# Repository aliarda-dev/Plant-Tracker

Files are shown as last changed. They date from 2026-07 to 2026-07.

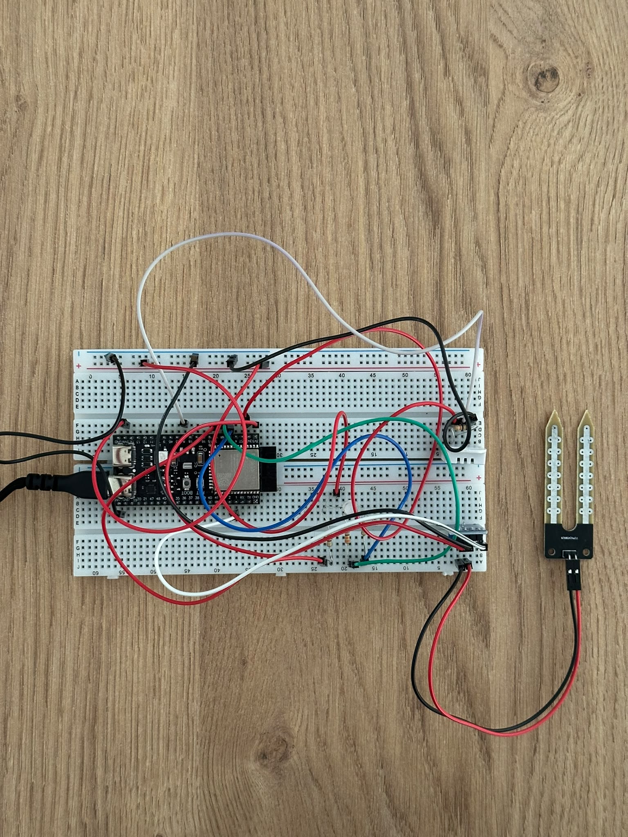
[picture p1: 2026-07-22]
Media/plant-tracker.jpeg

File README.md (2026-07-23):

***Plant Tracker***

DHT22 ve FC28 sensörlerini entegre çalıştırarak kodumda yazdığım koşullar sağlandığında telegram botuna mesaj yollayan bir IoT projesi. İlk IoT proje deneyimim oldu zorlandığım taraf ESP32'nin wifiye bağlaması oldu, buna gerçekten çok vakit ayırdım.

***Uğraştığım Hatalar***

* C make list mantığını biraz geç öğrendim bu yüzden compiler sürekli hata veriyordu
* Https sertifika hataları
* Main task overflow hatası, menucfonig defaultu 3584 bytedi ben bunu 8192 yaptim (https istekleri buna neden oldu)
* DHT22 Phase B hatası aldım. Çözümü delay kullanmak oldu wifi istekleri ile aynı anda kullanılınca sıkıntı çıkarabiliyor.
* RGB led 5V bağlı iken yanmıyordu. Sebebi ESP32'nin 5V çıkışının aktif olmamasıydı. Redditte dolaşmaktan projeden bıkmaya başlamıştım sonrasında kart üstündeki N-OUT köprüsünü öğrendim 5V güç çıkışı için bunun lehimlenmesi gerekiyormuş onu lehimledim.
* ve daha niceleri

***Donanım***

* ESP32S3
* DHT22 (Sıcaklık ve Nem sensörü)
* FC-28 (Toprak Nem Sensörü)
* Ortak Anot RGB Led
* 4x330R Direnç (Üç tanesi rgb led için geriye kalan bir tanesi de dht sensoru için)

***Nasıl Çalışır?***

* DHT22 sensöründen sıcaklık ve nem değerleri okunur ve gerekli variablelara aktarılır
* FC28 sensöründen nem değeri okunarak gerekli variablea aktarılır
* Wifi bağlantısı kurulur
* Belirlenen aralıkta telegram botuna bitkinin içinde bulunduğu odanın sıcaklık ve nem değerleri gönderilir
* Toprak nem değeri eşik değeri altına düşerse bota uyarı mesajı yollanır
* Sıcaklık ve nem değerleri belirlenen değerler dışına saparsa bota başka bir uyarı mesajı yollanır
* Zamanlama kontrolu olarak esp_timer_get_time() kullanılır

***Teknik Notlar***

* Wifi bağlantısı ve Telegram API kısmında AI'dan destek aldım. İlk IoT projem olduğu için ESP'nin ağ yapısını tek başıma kurmakta zorlandım. Kodu tamamladıktan sonra birkaç gün boyunca kullandığım her fonksiyonu ve event yapısını tek tek inceleyerek nasıl çalıştığını öğrenmeye çalıştım.

***Geliştirme Fikirleri***

* ESP32 hafızası üzerinde dosya açılarak hataların geldiği saatler data olarak tutulabilir.

🎥 Proje Demo

https://github.com/user-attachments/assets/45af9969-96e5-4f03-8e86-a813d68cf8f5

📷 Proje PCB Medyası

plant-tracker4

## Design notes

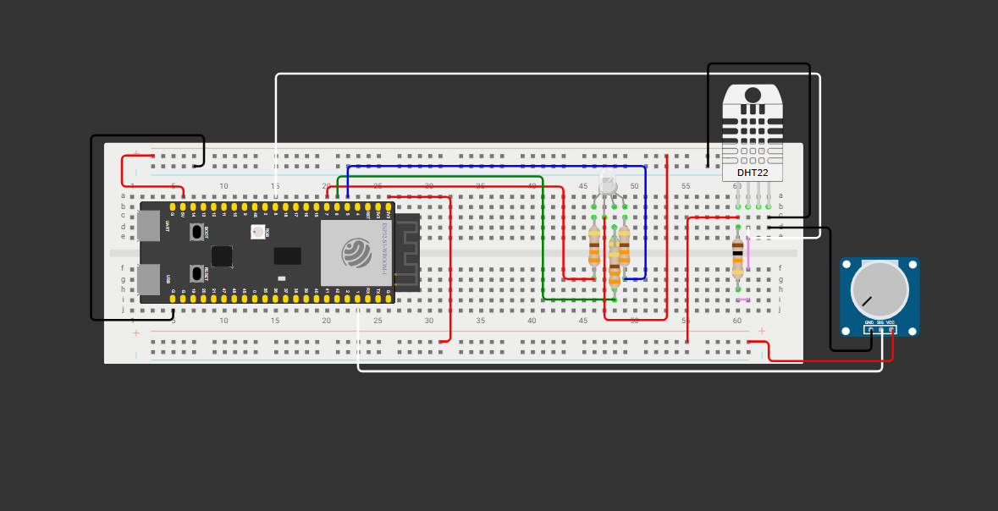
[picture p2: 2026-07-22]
Media/teoric-plant-tracker.png

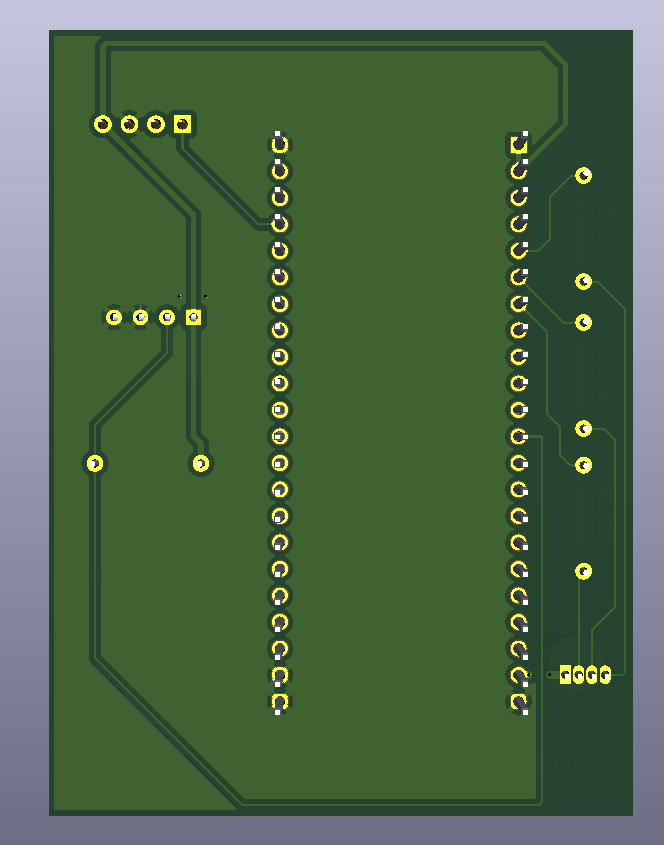
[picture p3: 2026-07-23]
PCB/PCB Media/plant-tracker2.png

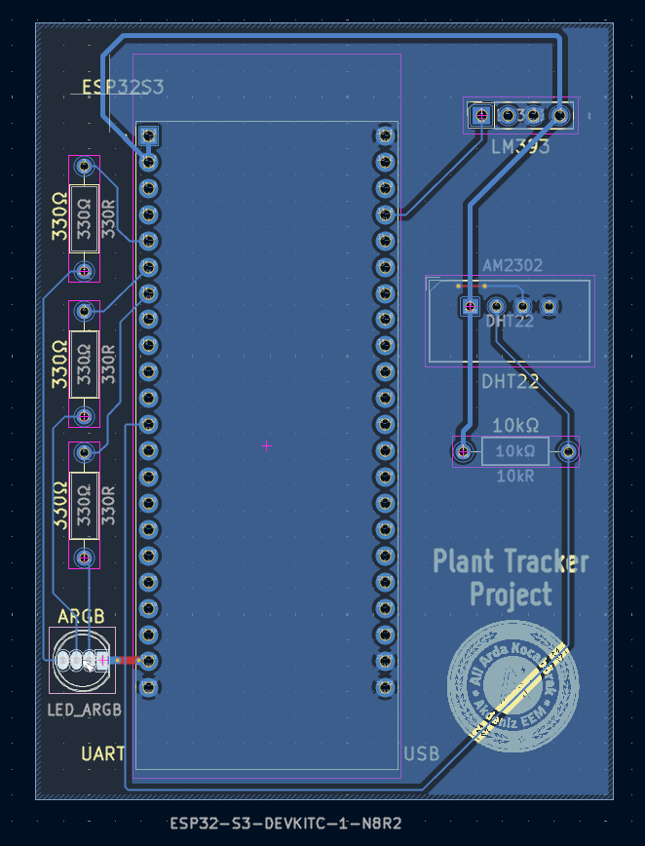
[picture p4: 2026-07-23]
PCB/PCB Media/plant-tracker3.png

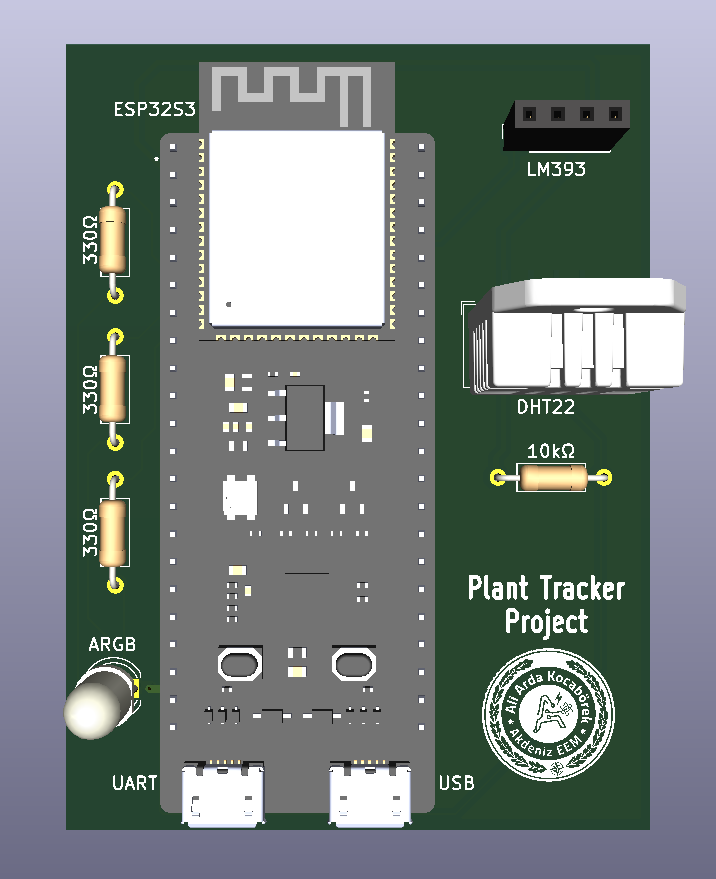
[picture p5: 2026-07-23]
PCB/PCB Media/plant-tracker1.png

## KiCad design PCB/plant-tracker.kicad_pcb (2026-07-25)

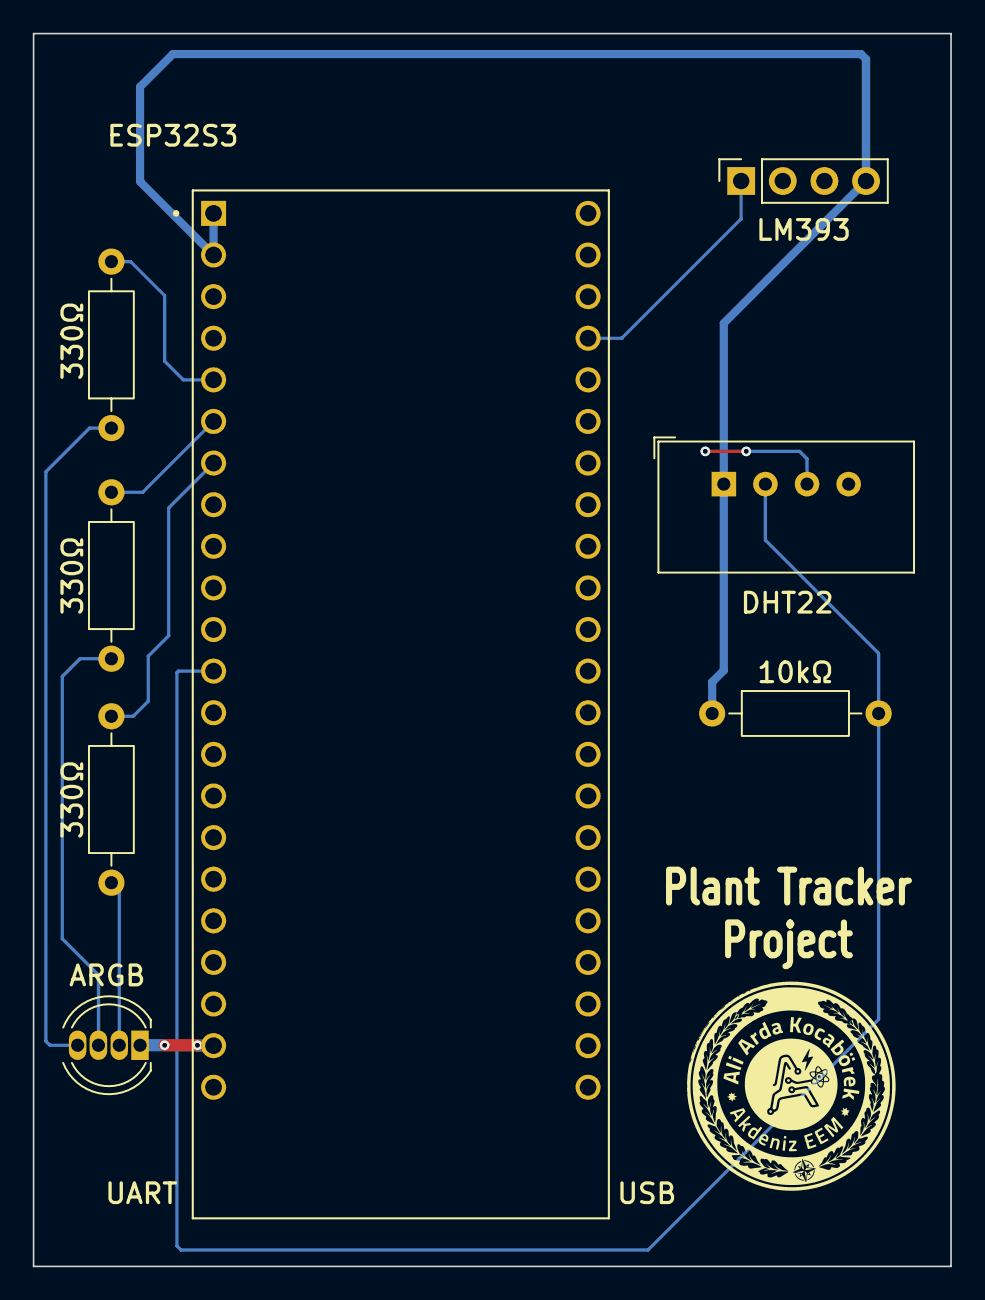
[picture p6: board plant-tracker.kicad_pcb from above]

Board: 2 copper layers, 56.0 x 75.2 mm, 8 parts (0 on the bottom side), 11 nets.

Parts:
10kΩ: 10kR; R_Axial_DIN0207_L6.3mm_D2.5mm_P10.16mm_Horizontal
330Ω, 330Ω#2, 330Ω#3: 330R; R_Axial_DIN0207_L6.3mm_D2.5mm_P10.16mm_Horizontal
ARGB: LED_ARGB; LED_D5.0mm-4_RGB
DHT22: AM2302; ASAIR_AM2302_P2.54mm_Vertical
ESP32S3: ESP32-S3-DEVKITC-1-N8R2; ESP32S3
LM393: PinSocket_1x04_P2.54mm_Vertical

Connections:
3.3V: 10kΩ.1, DHT22.1 (VDD), ESP32S3.J1_1 (3V3), ESP32S3.J1_2 (3V3), LM393.4 (VCC)
5V: ARGB.1 (A), ESP32S3.J1_21 (5V0)
G1: ESP32S3.J3_4 (GPIO1), LM393.1 (AO)
G5: 330Ω#2.2, ESP32S3.J1_5 (GPIO5)
G6: 330Ω#3.2, ESP32S3.J1_6 (GPIO6)
G7: 330Ω.2, ESP32S3.J1_7 (GPIO7)
G8: 10kΩ.2, DHT22.2 (SDA), ESP32S3.J1_12 (GPIO8)
GND: DHT22.3 (GND), DHT22.4 (GND), ESP32S3.J1_22 (GND), ESP32S3.J3_1 (GND), ESP32S3.J3_21 (GND), ESP32S3.J3_22 (GND), LM393.3 (GND)
unnamed: 330Ω#2.1, ARGB.4 (BK)
unnamed: 330Ω#3.1, ARGB.3 (GK)
unnamed: 330Ω.1, ARGB.2 (RK)

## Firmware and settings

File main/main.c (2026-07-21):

#include <stdio.h>
#include <string.h>
#include <stdbool.h>
#include "freertos/FreeRTOS.h"
#include "freertos/task.h"
#include "driver/gpio.h"
#include "dht.h"

#include "esp_wifi.h" //Wifi surucusu
#include "nvs_flash.h" //Wifi surucusunun bazi bilgileri burada tutulur
#include "esp_event.h" //Wifi baglantısı saglandı mi gibi kontrol eden fonksiyonlara sahip
#include "esp_log.h"
#include "esp_netif.h" //Wifinin TCP/IP katmani hazirlanmasi

#include "esp_http_client.h" //htpp istegi icin (telegram kullanicaz)
#include "esp_crt_bundle.h"

#include "esp_adc/adc_oneshot.h" //Toprak nem sensoru icin

#include "esp_timer.h"









#define WIFI_SSID "xxxx" //wifi adi
#define WIFI_PASS "xxxx" //wifi sifre 

#define BOT_TOKEN "xxx" //telegram bot token
#define CHAT_ID "xxx" //telegram bot chat id

#define MAVI_LED GPIO_NUM_5
#define YESIL_LED GPIO_NUM_6
#define KIRMIZI_LED GPIO_NUM_7

#define TOPRAK_PIN ADC_CHANNEL_0
adc_oneshot_unit_handle_t adc_handle;


#define DHT22_PIN GPIO_NUM_8

static const char *TAG = "WiFi"; //Loglarda gorunecek isim
static void wifi_event_handler( //Espnin olay kontrol dongusunu kontrol eden fonksiyon
        void *arg,
        esp_event_base_t event_base,
        int32_t event_id,
        void *event_data);
void wifi_init(void);        

bool DhtDegerler (float*,float*);

void telegram_message(const char *);

void toprakPin_init(void);
void toprakDeger(int*);



void app_main(void){

    gpio_set_direction(MAVI_LED,GPIO_MODE_OUTPUT);
    gpio_set_direction(YESIL_LED,GPIO_MODE_OUTPUT);
    gpio_set_direction(KIRMIZI_LED,GPIO_MODE_OUTPUT);



    wifi_init();
    toprakPin_init();

    vTaskDelay(pdMS_TO_TICKS(8000));


    float sicaklik=0;
    float nem=0;

    int toprakDegeri=0;
    int esikDegeri=4000;

    
    int64_t son_mesaj_zaman_sicaklik=0;
    int64_t son_mesaj_zaman_sulama=0;
    int64_t son_mesaj_zaman_havaKosul=0;

    const int64_t mesaj_aralik=10*60*1000000; //10 dakika esp timera baglı bu hesaplama

     gpio_set_level(MAVI_LED,1);
     gpio_set_level(YESIL_LED,1);
     gpio_set_level(KIRMIZI_LED,1);


            

    while(1){

        bool sensor_kontrol=DhtDegerler(&sicaklik,&nem);

        vTaskDelay(pdMS_TO_TICKS(5000)); 

         if(sensor_kontrol==false){
            printf("DHT okunamadi hata!!\n\n");
            continue;
        }

        int64_t simdi=esp_timer_get_time();

        if(gpio_get_level(KIRMIZI_LED)==0){
            gpio_set_level(KIRMIZI_LED,1);
        }

        if(simdi-son_mesaj_zaman_sicaklik>mesaj_aralik){ //istedigimiz aralikta odanin kosullarini telegrama gonderecegiz

            char mesaj[50];

            snprintf(mesaj,sizeof(mesaj),"Sicaklik %.2f'C | Nem %.2f/100",sicaklik,nem);

            telegram_message(mesaj);

            son_mesaj_zaman_sicaklik=simdi;
        }





        toprakDeger(&toprakDegeri);
        vTaskDelay(pdMS_TO_TICKS(1000));

        if(toprakDegeri<esikDegeri && simdi-son_mesaj_zaman_sulama>mesaj_aralik/2){ //5 dakika
            telegram_message("Bitkinizi acil sulayin!!!");
            gpio_set_level(YESIL_LED,0);
            vTaskDelay(pdMS_TO_TICKS(500));
            gpio_set_level(YESIL_LED,1);

            son_mesaj_zaman_sulama=simdi;
        }

        if((sicaklik>40 || nem>80 || nem<30) && simdi-son_mesaj_zaman_havaKosul>mesaj_aralik/2){ //5 dakika
            telegram_message("Bitkiniz icin gerekli hava kosullari saglanmiyor!");
            gpio_set_level(KIRMIZI_LED,0);
            son_mesaj_zaman_havaKosul=simdi;
        }


        vTaskDelay(pdMS_TO_TICKS(5000));


        
    }

    



}






bool DhtDegerler (float* sicaklik,float* nem){

    esp_err_t sonuc = dht_read_float_data(DHT_TYPE_AM2301,DHT22_PIN,nem,sicaklik);

    if(sonuc==ESP_OK){
        printf("Sicaklik: %.2f\n",*sicaklik);
        printf("Nem: %.2f",*nem);
        vTaskDelay(pdMS_TO_TICKS(3500));
        return true;
    }

    else{
        printf("DHT duzgun calismiyor!!\n");
        return false;
    }

    

}



static void wifi_event_handler( //Espnin olay kontrol dongusunu kontrol eden fonksiyon
        void *arg,
        esp_event_base_t event_base,
        int32_t event_id,
        void *event_data){

            if(event_base==WIFI_EVENT && event_id==WIFI_EVENT_STA_START){ //Wifi surucusu basladiysa

                ESP_LOGI(TAG,"Wi-fi Basladi!\n\n");

                esp_wifi_connect();

            } 

            else if(event_base==WIFI_EVENT && event_id==WIFI_EVENT_STA_DISCONNECTED){

                ESP_LOGI(TAG,"Baglanti Koptu Tekrar Deneniyor...\n\n");

                esp_wifi_connect();
            }

            else if(event_base==IP_EVENT && event_id==IP_EVENT_STA_GOT_IP){ //IP alındıgında

                ESP_LOGI(TAG,"Wi-fi baglandi ve ip alindi...\n\n");
            }

        }



void wifi_init(void){

        nvs_flash_init(); //Flash bellek hazirlanmasi

        esp_netif_init(); //TCP_IP katmanini baslatilmasi

        esp_event_loop_create_default(); //Event sisteminin olusturulmasi

        esp_netif_create_default_wifi_sta(); //Station arayuzunun olusmasi


        wifi_init_config_t cfg = WIFI_INIT_CONFIG_DEFAULT(); //Wifi driver ayarlari

        esp_wifi_init(&cfg); //Driveri baslatma


        esp_event_handler_instance_register(WIFI_EVENT,ESP_EVENT_ANY_ID,&wifi_event_handler,NULL,NULL); //Wifi Event Dinleme (Wifi event handler fonksiyonunu kullandıgımız yer)

        esp_event_handler_instance_register(IP_EVENT,IP_EVENT_STA_GOT_IP,&wifi_event_handler,NULL,NULL); //IP Event Dinleme


        wifi_config_t wifi_config = { //Wifi Bilgileri
            .sta={
                .ssid=WIFI_SSID,
                .password=WIFI_PASS,
            },
        };

        esp_wifi_set_mode(WIFI_MODE_STA); //Station modu gecis

        esp_wifi_set_config(WIFI_IF_STA,&wifi_config); //Ayarları yukleme

        esp_wifi_start(); //Wi-fi surucusunu baslatma

}        


void telegram_message(const char *message){

    char url[512];

    snprintf(url,sizeof(url),"https://api.telegram.org/bot%s/sendMessage",BOT_TOKEN);



    char mesajiniz[512];

    snprintf(mesajiniz,sizeof(mesajiniz),"chat_id=%s&text=%s",CHAT_ID,message);

    esp_http_client_config_t config={.url=url,.crt_bundle_attach=esp_crt_bundle_attach,};

    esp_http_client_handle_t client=esp_http_client_init(&config);

    
    if(client==NULL) printf("Client olusturulamadi!\n");

    esp_http_client_set_method(client,HTTP_METHOD_POST);

    esp_http_client_set_header(client,"Content-Type","application/x-www-form-urlencoded");

    esp_http_client_set_post_field(client,mesajiniz,strlen(mesajiniz));

    esp_err_t err=esp_http_client_perform(client);


    if(err==ESP_OK) printf("Mesaj gonderildi..\n");

    else printf("Hata %s\n",esp_err_to_name(err));


    esp_http_client_cleanup(client);
}


void toprakPin_init(void){

    adc_oneshot_unit_init_cfg_t init_config={.unit_id=ADC_UNIT_1};

    ESP_ERROR_CHECK(adc_oneshot_new_unit(&init_config,&adc_handle));

    adc_oneshot_chan_cfg_t config={.bitwidth=ADC_BITWIDTH_DEFAULT,.atten=ADC_ATTEN_DB_12};

    ESP_ERROR_CHECK(adc_oneshot_config_channel(adc_handle,TOPRAK_PIN,&config));
}


void toprakDeger(int* deger){

    ESP_ERROR_CHECK(adc_oneshot_read(adc_handle,TOPRAK_PIN,deger));

    printf("Toprak ADC: %d\n",*deger);
}

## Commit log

2026-07-22 Added PCB Media
2026-07-22 Added Gerber Files
2026-07-23 PCB Media Added
2026-07-25 Gerber Files Added
    [plant-tracker-B_Cu.gbr, plant-tracker-B_Mask.gbr, plant-tracker-B_Paste.gbr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]
2026-07-25 DRL Files Added
    [plant-tracker.kicad_pcb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]
2026-07-25 Fabrication Zip for PCB
2026-07-25 PCB Files
